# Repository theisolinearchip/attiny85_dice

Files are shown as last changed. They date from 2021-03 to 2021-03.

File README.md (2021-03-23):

# attiny85_dice

I started this project to learn more about how to design a PCB from scratch, so I wrote two different sets of dice in order to flash them into a couple of attiny85's.

- **d1ce** is a single d6 dice that uses 7 leds to show each dot. A **standard 8-bit shifter** is used to control the different sides
- **dic3** is a three-dice-pack that uses different led segments to display numeric values up to 99. It uses a **max7219** to control the numbers and it allows different sides for each dice (so you can "roll" one d20 and two d8, for example)

Both work in a *similar* way:

1. There's a timer running non-stop incrementing a *seed value* that it's used as a seed for the random functions
2. On each "roll" the seed is changed to the current *seed value* and a random value (or values) is picked
3. A second timer handles the "animation" of a dice rolling (or numbers changing)
4. The final value is shown

This was one of my first approach on timers and interrupts for the AVRs micros, so I'm sure there are lots of improvements that can be made.

Maybe using a timer to set a random seed is not the best way to handle it, but for simple picks for a dummy dice I think it's enough; and to prevent having only one "initial value", the seed changes on every roll (otherwise -if we set the seed **only** on the beginning, for example- it's more likely to have two "equal dice" only by matching that initial roll).

## d1ce
The d6 dice was the first one and it's a single *dice.c* file that handles all the interrupts, timers and 8-bit shifter operations (three pins on that: *data*, *clock* and *latch*).

There's also a couple of schematic files and the gerbers I used to order the board on one of those external prototyping services. The PCB seems to work fine, but I made a small mistake when setting the power switch, so it's not properly aligned to the right (but it's fully functional).

## dic3
The three-in-one dice it's similar to the single d6 one (it's based on the same code) but there's an aditional **max7219drv.c** file that implements a couple of methods to control the max7219 that handles the three numeric led displays.

It also has a "config mode" with a secondary button that allows the user to individually change the dice values.

Here there's only the schematic files but not the gerbers, since the PCB I made uses a space for a *2032 battery holder* (a small 3V coin battery, the same as the one used on **d1ce**) but the requirements for the **max7219** demands 5v (more or less). I totally forgot about this, so in return I have a fully functional PCB that needs to be hooked up to an external 5v source or, at least, do some creativity with other components to make it work :_ D

## Useful links
[https://embeddedthoughts.com/2016/06/06/attiny85-introduction-to-pin-change-and-timer-interrupts/](https://embeddedthoughts.com/2016/06/06/attiny85-introduction-to-pin-change-and-timer-interrupts/) Some interrupts and timers info

[https://tinusaur.org/2019/01/06/interfacing-a-max7219-driven-led-matrix-with-attiny85/](https://tinusaur.org/2019/01/06/interfacing-a-max7219-driven-led-matrix-with-attiny85/) **max7219** with attiny85

[https://docs.kicad.org/5.1/en/getting_started_in_kicad/getting_started_in_kicad.html](https://docs.kicad.org/5.1/en/getting_started_in_kicad/getting_started_in_kicad.html) I followed the "Getting started" section from the **KiCad docs** to learn the basics about the whole process of designing and making the boards

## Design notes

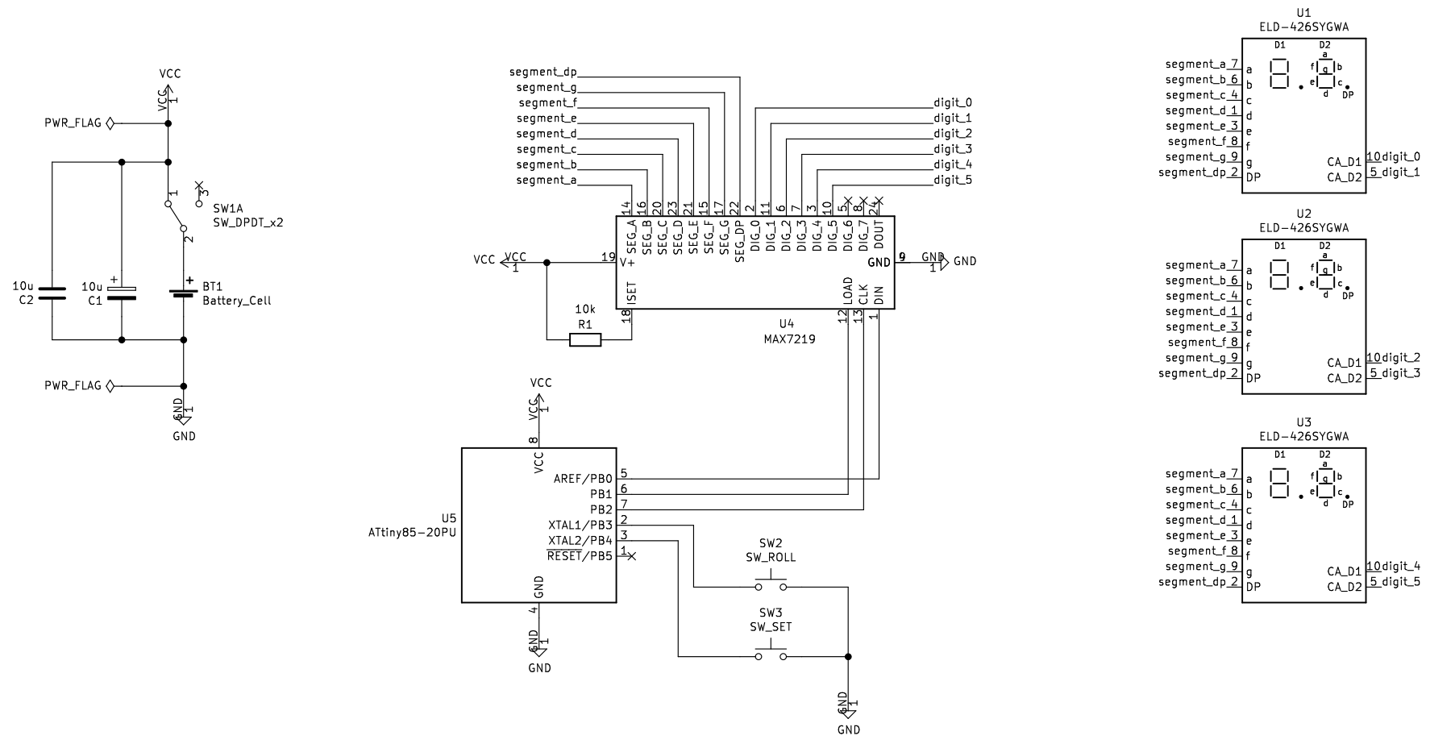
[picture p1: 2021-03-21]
dice_3/design/schematics.png

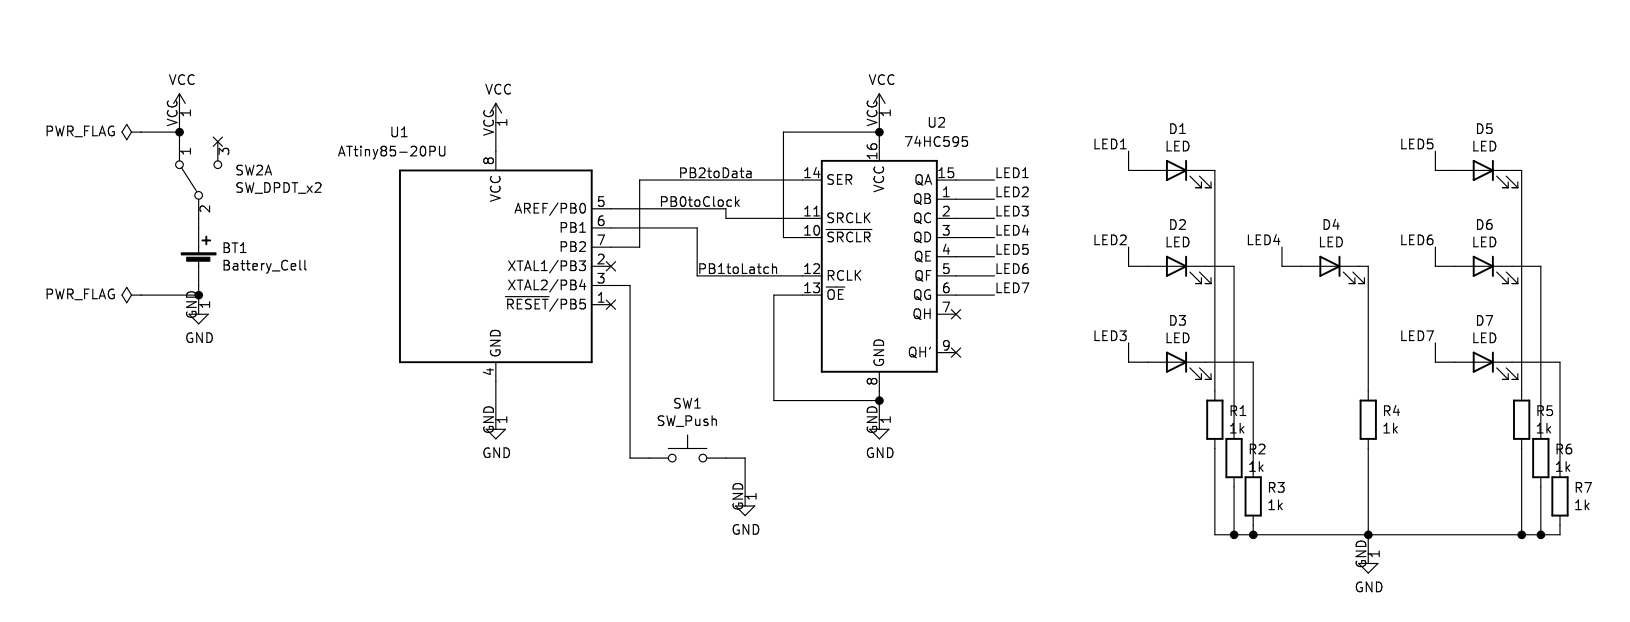
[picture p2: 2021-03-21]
dice_1/design/schematics.png

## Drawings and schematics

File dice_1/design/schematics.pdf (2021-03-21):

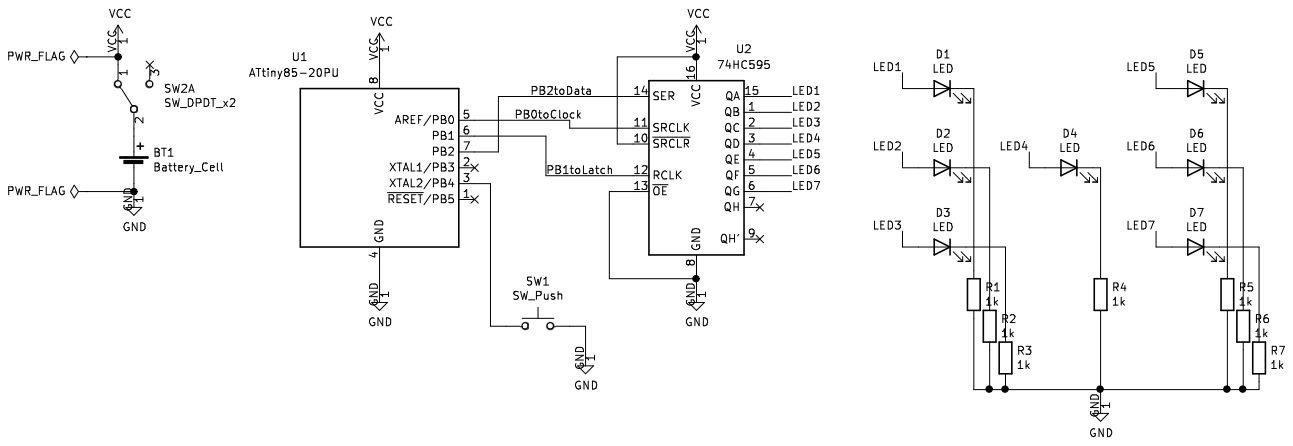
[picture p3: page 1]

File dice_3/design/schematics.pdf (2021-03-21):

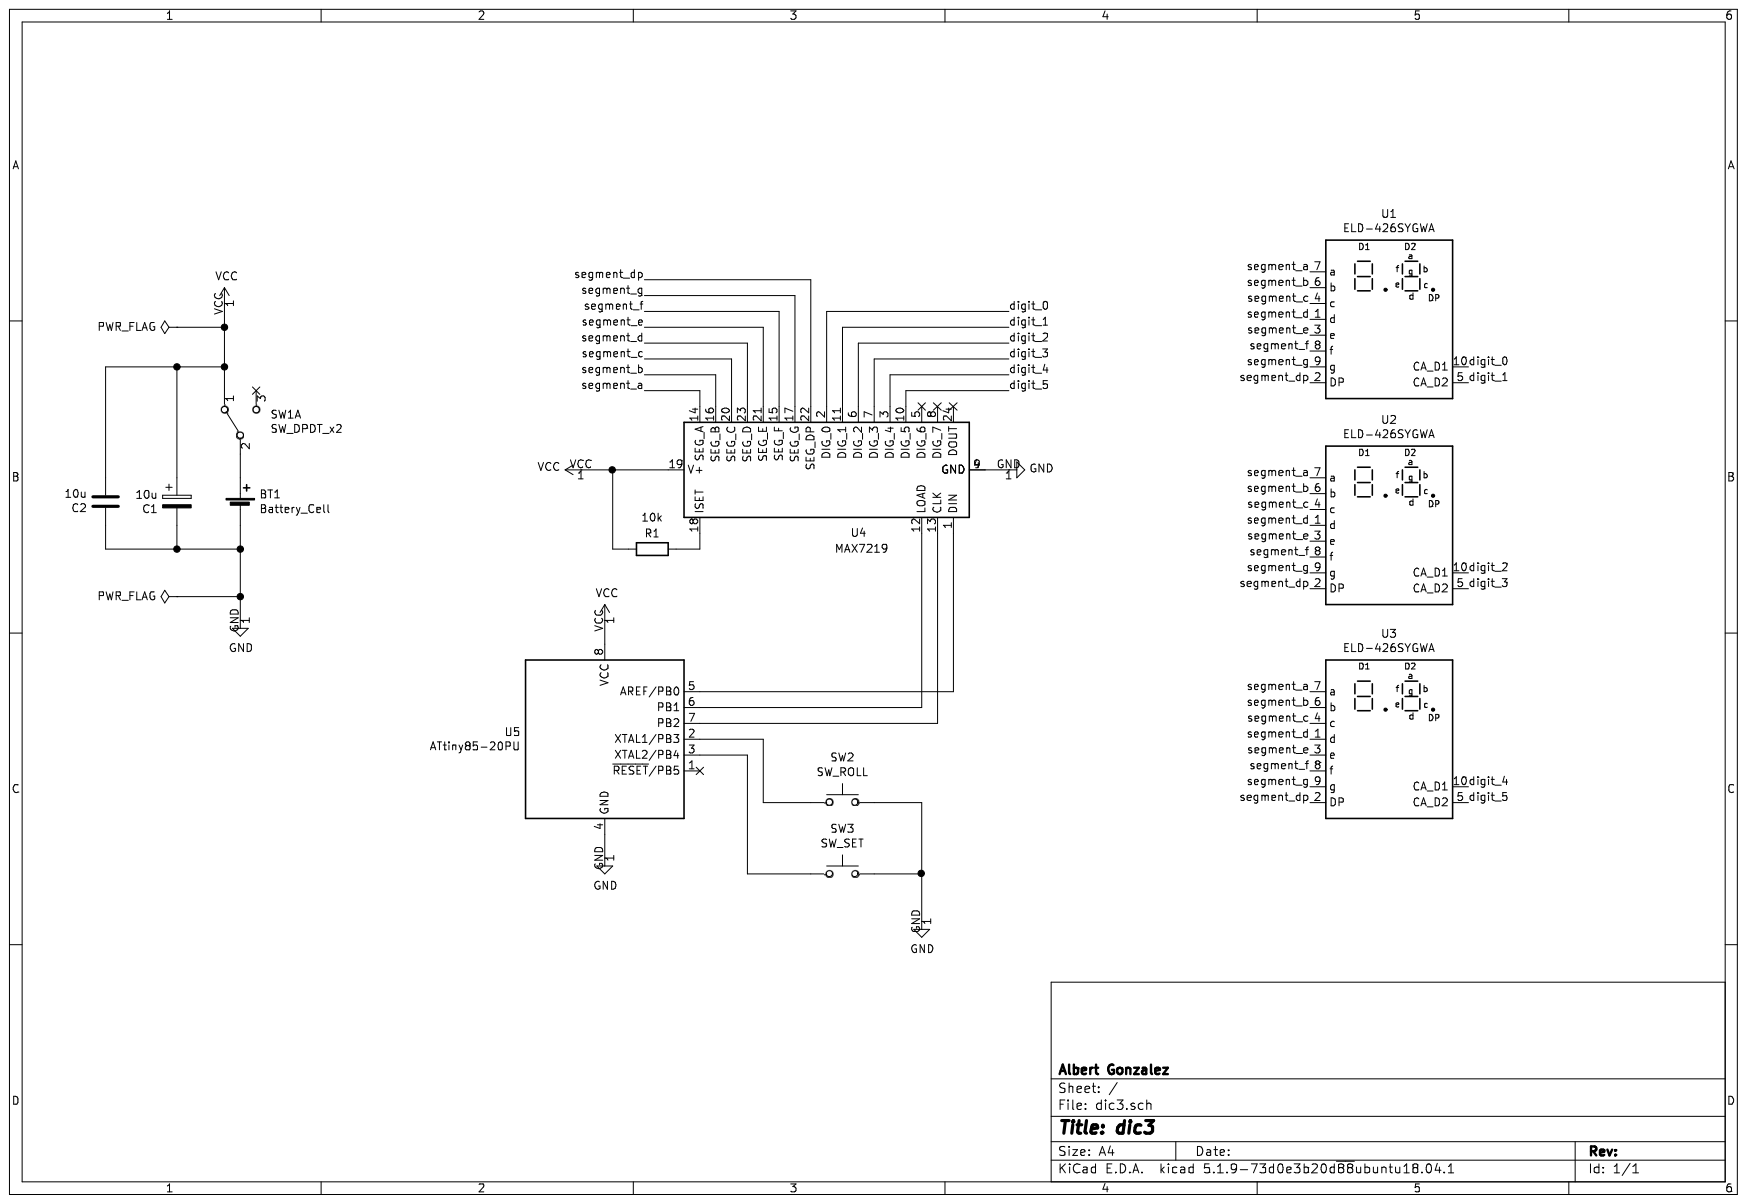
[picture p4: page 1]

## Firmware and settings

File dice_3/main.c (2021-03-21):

#include <avr/io.h>
#include <util/delay.h> 
#include <avr/interrupt.h>
#include <stdlib.h>

#include "max7219drv.c"

#define		PORT_BUTTON_ROLL	PB3
#define		PIN_BUTTON_ROLL		PIN3
#define		PORT_BUTTON_SET		PB4
#define		PIN_BUTTON_SET		PIN4

static char state = 0; // 0 display something / 1 rolling / 2 setting values

static char button_roll_pressed = 0;
static char button_roll_previously_pressed = 1;
static char button_set_pressed = 0;
static char button_set_previously_pressed = 1;

static char waiting_for_release = 1;

volatile unsigned int seed = 0;

// dices
const char dice_sides_length = 6;
const char dice_sides[6] = {4, 6, 8, 10, 12, 20};

static char dice_values[3] = { -1, -1, -1 };
static char dice_rolling_value[3] = { -1, -1, -1 };
static char dice_sides_index[3] = { 5, 5, 5 }; // index for 20-sides dice

// set mode
static int index_dice_set = 0;

// timers and stuff
volatile int ticks_interval_rolling = 2;
volatile int total_intervals_rolling = 30; // 30 * 2 ~= 122/2 (half of a sec according to preescaler + freq)
volatile int current_intervals_rolling = 0;

void prepare_interrupts() {
	/*
		presescaler at 8192, so frequency / preescaler:
		We're running at 1Mhz, so:

		1*10^6 / 8192 = 122,0703...

		That means we can "reach" 1 second every 122ish ticks/cicles/interrupts,
		so to trigger the ISR every second, OCR1C = 122;

		https://embeddedthoughts.com/2016/06/06/attiny85-introduction-to-pin-change-and-timer-interrupts/
	*/
	
	// timer 0 used on the first button press to get a random seed
	TCCR0A = (1 << WGM01); // CTC, compares with OCR0A, see datasheet
	OCR0A = 1;

	// timer 1 used	for the rolling time
	TCCR1 |= (1 << CTC1); // reset after comparing with OCR1C (only C!)
	OCR1C = ticks_interval_rolling;
	
	TIMSK = (1 << OCIE0A) | (1 << OCIE1A) ; // enable compare match interrupts

	sei();	
}

void start_timer0() {
	TCCR0B = (1 << CS02) | (1 << CS00);  // prescaler / 1024
	// do not clear TCNT0 like in timer1 since this will be called
	// only one time, so it'll be always 0
}

void stop_timer0() {
	TCCR0B = 0; // set everything to 0 (the others values doesn't mind here)
}

void start_timer1() {
	TCCR1 |= (1 << CS13) | (1 << CS12) | (1 << CS11); //clock prescaler 8192
	// clear the current time counter in case we have something from the last time
	// (the value will be reset on each comparison thanks to the CTC mode but if
	// we didn't reach the last one before disabling the timer, some middle
	// value may persist there, so we best start at 0 each time)
	TCNT1 = 0;
}

void stop_timer1() {
	TCCR1 = (1 << CTC1); // no clock source, just keep the CTC1 (clear the CS)
}

ISR(TIMER0_COMPA_vect) {
	// doesn't mind if we overflow this one, we just wanna have
	// a "random" value between powering up and the first click;
	// it'll be a "debounce" function to avoid keeping the button
	// pressed while turning it on
	seed++;
}

// waiting
void waiting_start() {
	waiting_for_release = 1;
	state = 0;
}

// rolling
void roll_start() {
	// set final values at the beginning (according to each dice total sides)
	for (int i = 0; i < 3; i++) {
		dice_values[i] = (rand() % dice_sides[ (int) dice_sides_index[i] ]) + 1;
	}
	current_intervals_rolling = 0;

	state = 1;

	start_timer1();
}

void roll_stop() {
	stop_timer1();
	state = 0;
}

void roll_animate(int dice) {
	// get some random value given the current dice sides (avoid repeating the same previous value by adding 2)
	int sides = dice_sides[ (int) dice_sides_index[dice] ];
	char previous_value = dice_rolling_value[dice];

	dice_rolling_value[dice] = (rand() % sides) + 1;
	if (dice_rolling_value[dice] == previous_value) {
		dice_rolling_value[dice] = (dice_rolling_value[dice] + 2) % sides;
	}
}

// set mode
void setmode_start() {
	waiting_for_release = 1;
	index_dice_set = 0; // reset index

	state = 2;
}

void setmode_change_index_dice() {
	index_dice_set++;
	if (index_dice_set > 2) index_dice_set = 0;
}

void setmode_change_sides_dice() {
	dice_sides_index[index_dice_set]++;
	if (dice_sides_index[index_dice_set] >= dice_sides_length) dice_sides_index[index_dice_set] = 0;
}

ISR(TIMER1_COMPA_vect) {
	current_intervals_rolling++;
	if (current_intervals_rolling >= total_intervals_rolling) {
		roll_stop();
	} else {
		roll_animate(0);
		roll_animate(1);
		roll_animate(2);
	}
}

void proccess_inputs() {
	switch(state) {
		default:
			break;
		case 0: // waiting for roll / set

			if (waiting_for_release && !button_set_pressed && !button_roll_pressed) {
				// debounce between mode: when entering this mode the buttons need
				// to be released in order to continue. Meanwhile we're stucked here
				waiting_for_release = 0;

			} else if (
				!button_set_pressed && !button_set_previously_pressed &&
				button_roll_pressed && !button_roll_previously_pressed
			) {
				// add seed
				srand(seed);

				roll_start();

			} else if (
				button_set_pressed && !button_set_previously_pressed &&
				!button_roll_pressed && !button_roll_previously_pressed
			) {
				setmode_start();
			}

			break;
		case 2: // set mode

			if (waiting_for_release && !button_set_pressed && !button_roll_pressed) {
				waiting_for_release = 0;
				
			} else if (
				!button_set_pressed && button_set_previously_pressed &&
				!button_roll_pressed && !button_roll_previously_pressed
			) {
				// change the current dice
				setmode_change_index_dice();
			} else if (
				!button_set_pressed && !button_set_previously_pressed &&
				!button_roll_pressed && button_roll_previously_pressed
			) {
				// change current dice sides
				setmode_change_sides_dice();
			} else if
			(
				button_set_pressed && button_roll_pressed
			) {
				// exit set mode
				waiting_start();
			}

			break;
	}
}

void show_numbers(char number, char digit_register_first, char digit_register_second, char decimal_point) {
	char first_value = 0x0F; // blank by default (no DP)
	char second_value = 0x0F; // blank by default (no DP)

	if (number > -1) {
		if (number < 10) {
			first_value = 0x00;
			second_value = number;
		} else {
			first_value = number / 10;
			second_value = number % 10;
		}
	}

	if (decimal_point) {
		second_value |= 0x80;
	}

	max7219_send_word(digit_register_first, first_value);
	max7219_send_word(digit_register_second, second_value);
}

void process_display() {
	// in set mode show the dice sides (add DP to the one selected by index_dice_set)
	// in waiting mode show the current value
	// in roll mode show the display-when-rolling value

	char val_0 = -1;
	char val_1 = -1;
	char val_2 = -1;

	switch(state) {
		default:
			break;
		case 0:
			val_0 = dice_values[0];
			val_1 = dice_values[1];
			val_2 = dice_values[2];
			break;
		case 1:
			val_0 = dice_rolling_value[0];
			val_1 = dice_rolling_value[1];
			val_2 = dice_rolling_value[2];
			break;
		case 2:
			val_0 = dice_sides[ (int) dice_sides_index[0] ];
			val_1 = dice_sides[ (int) dice_sides_index[1] ];
			val_2 = dice_sides[ (int) dice_sides_index[2] ];
			break;
	}

	show_numbers(val_0, MAX7219_REG_DIGIT_0, MAX7219_REG_DIGIT_1, (state == 2 && index_dice_set == 0) );
	show_numbers(val_1, MAX7219_REG_DIGIT_2, MAX7219_REG_DIGIT_3, (state == 2 && index_dice_set == 1) );
	show_numbers(val_2, MAX7219_REG_DIGIT_4, MAX7219_REG_DIGIT_5, (state == 2 && index_dice_set == 2) );
}

int main(void) {

	// DDRB &= ~(1 << PORT_BUTTON_SET); // input mode by default, no need to do that
	PORTB |= (1 << PORT_BUTTON_SET); // activate pull up on PB4 (use PORTB since now it's on input mode)
	PORTB |= (1 << PORT_BUTTON_ROLL);

	// init max7219 stuff
	max7219_init(); 

	max7219_send_word(MAX7219_REG_DEC_MODE, 0xFF); // 00 = No decode, FF decode
    max7219_send_word(MAX7219_REG_INTENSITY, 0x0F); // Intensity from 0x00 to 0x0F (max)
    max7219_send_word(MAX7219_REG_SCAN_LIMIT, 0x05); // digits from 0 to 5 (six digits)
    max7219_send_word(MAX7219_REG_SHUTDOWN, 0x01); // 0x01 normal operation, 0x00 shutdown
    max7219_send_word(MAX7219_REG_DISPLAY_TEST, 0x00); // Test mode OFF

    prepare_interrupts();
	start_timer0();

	while(1) {
		button_roll_pressed = !(PINB & (1 << PIN_BUTTON_ROLL));
		button_set_pressed = !(PINB & (1 << PIN_BUTTON_SET));

		proccess_inputs();
		process_display();

		button_roll_previously_pressed = button_roll_pressed;
		button_set_previously_pressed = button_set_pressed;
	}

}

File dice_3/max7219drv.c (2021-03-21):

/*
	max7219 communication based on
	https://tinusaur.org/2019/01/06/interfacing-a-max7219-driven-led-matrix-with-attiny85/
*/

#ifndef max7219Driver_c
#define max7219Driver_c

#define MAX7219_DATA				0		// pin 1
#define MAX7219_LOAD				1 		// pin 12
#define MAX7219_CLK					2 		// pin 13

#define MAX7219_REG_NOOP			0x00
#define MAX7219_REG_DIGIT_0			0x01
#define MAX7219_REG_DIGIT_1			0x02
#define MAX7219_REG_DIGIT_2			0x03
#define MAX7219_REG_DIGIT_3			0x04
#define MAX7219_REG_DIGIT_4			0x05
#define MAX7219_REG_DIGIT_5			0x06
#define MAX7219_REG_DIGIT_6			0x07
#define MAX7219_REG_DIGIT_7			0x08
#define MAX7219_REG_DEC_MODE		0x09
#define MAX7219_REG_INTENSITY		0x0A
#define MAX7219_REG_SCAN_LIMIT		0x0B
#define MAX7219_REG_SHUTDOWN		0x0C
#define MAX7219_REG_DISPLAY_TEST	0x0F

void max7219_init() {
	DDRB |= (1 << MAX7219_DATA);
	DDRB |= (1 << MAX7219_LOAD);
	DDRB |= (1 << MAX7219_CLK);
}

void max7219_send_bit(uint8_t bit) {
	PORTB &= ~(1 << MAX7219_CLK);
	if (bit) {
		PORTB |= (1 << MAX7219_DATA); // HIGH
	} else {
		PORTB &= ~(1 << MAX7219_DATA); // LOW
	}
	PORTB |= (1 << MAX7219_CLK);
}

void max7219_send_byte(uint8_t byte) {
	for (uint8_t bit = 0; bit < 8; ++bit) {
		max7219_send_bit((byte & 0x80) != 0); // msb, start sending from the left
		byte <<= 1;
	}
}

void max7219_send_word(uint8_t address, uint8_t data) {
	PORTB &= ~(1 << MAX7219_LOAD);
	max7219_send_byte(address);
	max7219_send_byte(data);
	PORTB |= (1 << MAX7219_LOAD);
}
#endif
